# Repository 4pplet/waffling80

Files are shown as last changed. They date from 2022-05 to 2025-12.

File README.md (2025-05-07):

# Waffling80

Waffling80 is a multilayout TKL PCB with support for common ANSI and ISO layouts and split space. The goal is to provide a open source alternative that is compatible with many common TKL projects.

The project is split into four different PCB designs. Two MX-versions with different spacebar rotation, one ALPS-versions with north facing spacebar rotation (MX-style PCB mount stabs) and one HiTek-version.

***NOTE: This project is still mostly untested, check compatibility list. *** If you test this project in a case not listed in the compatiblity list. Please let me know here or at mail@4pplet.com

The distance between plate and PCB for a Hi-Tek board is 0.6mm bigger than a normal MX/Alps PCB.

Verified compatibility list: [Link](./COMPAT.md)

## Features:
- QMK & VIA
- USB-C break away
- APM or STM32F072
- RGB-led under/close to caps lock and scroll lock for MX and Alps-versions (requires transparent housings)
- On ALPS-version: Dual action switch support on ESC and Pause/Break switch positions.
- On MXHS-version: Capslock indicator led is placed at ESC switch position.
- Extensive layout support with F12 and F13, ISO and ANSI and more.

## Todo:
- Test compatibility in cases.

## Layout support - Solder PCB: 
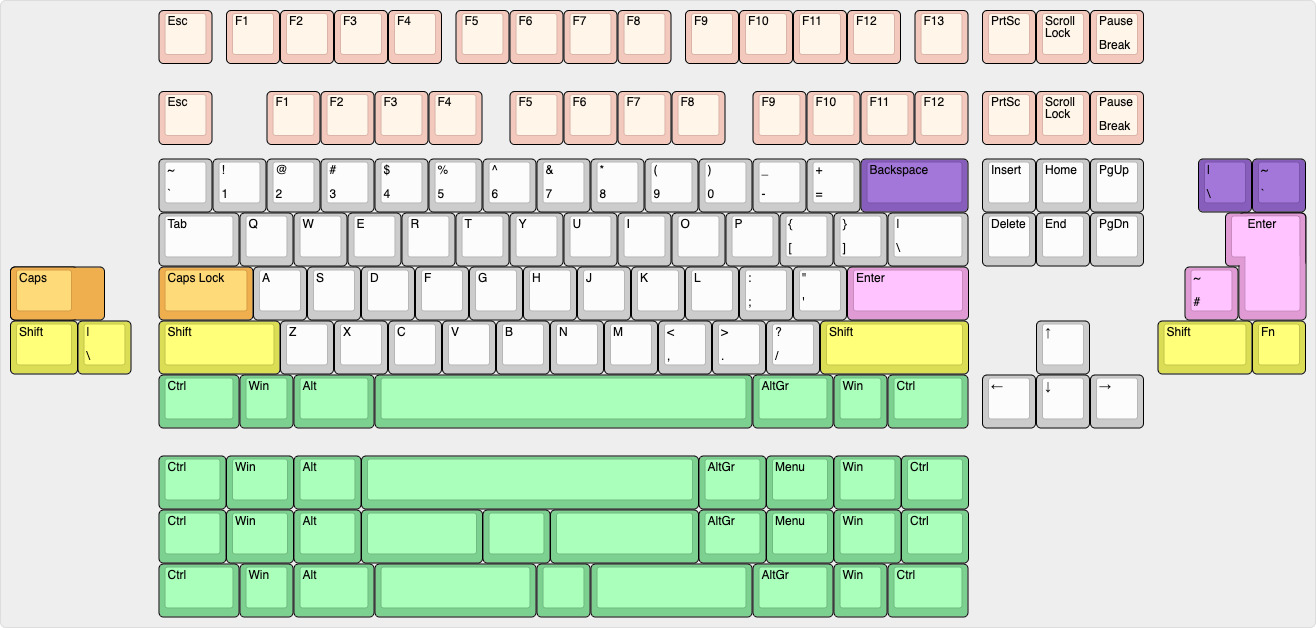
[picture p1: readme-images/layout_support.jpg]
Layout support - Solder


## Layout support - Hot swap PCB: 
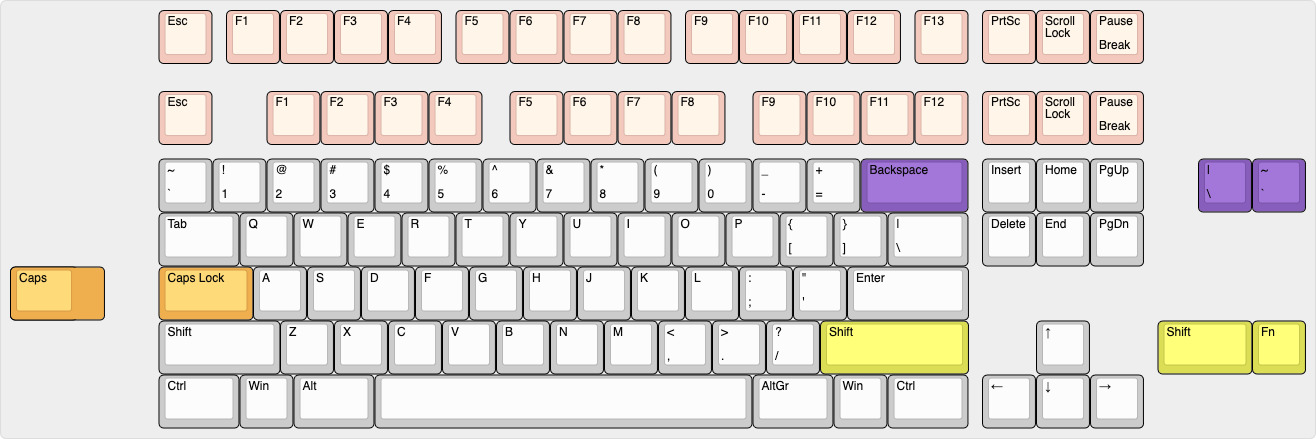
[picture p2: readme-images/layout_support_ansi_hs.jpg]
Layout support - Hot swap


## MX - North: 
MX - North
## MXHS - North: 
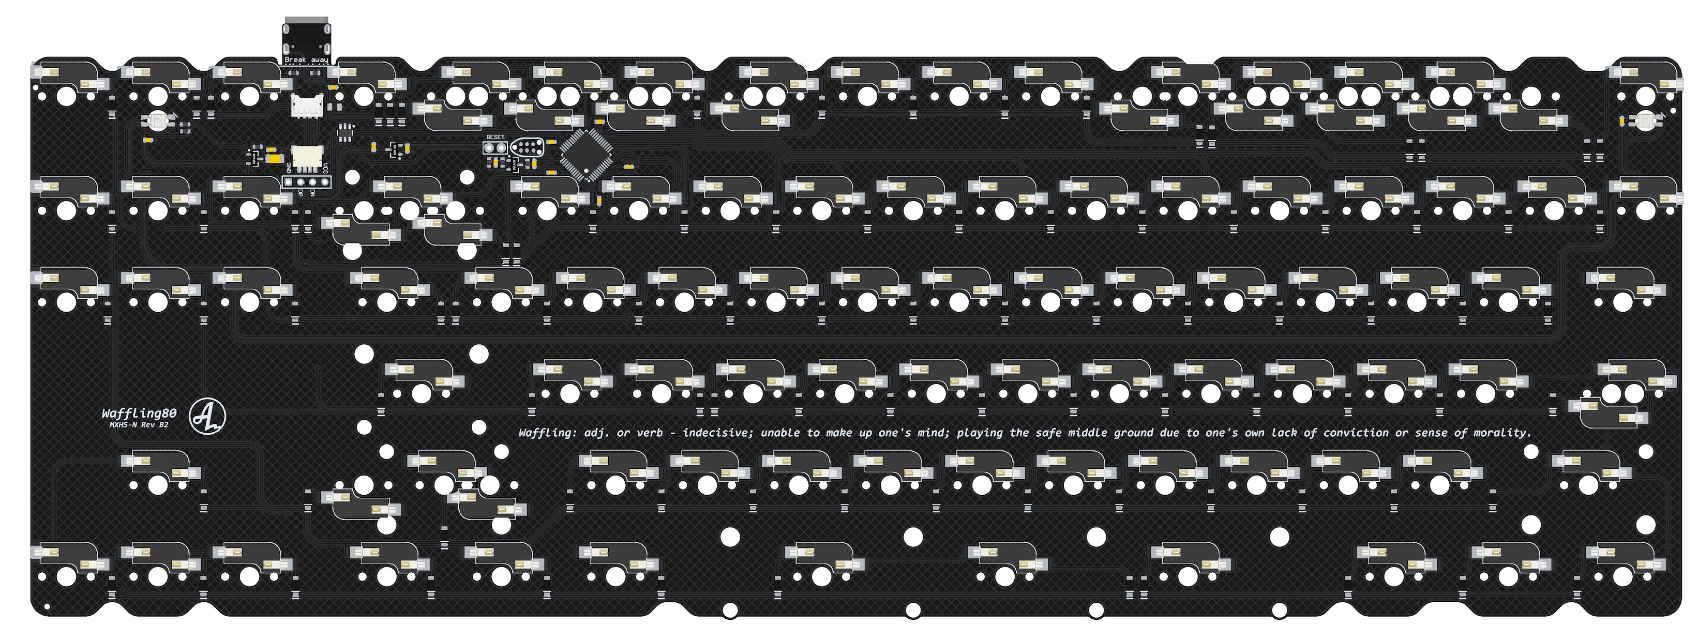
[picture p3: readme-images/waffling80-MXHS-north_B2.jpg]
MXHS - North

## MX - South:
MX - South
## ALPS:
ALPS
## NMB HiTek:
HiTek

## For ordering:
The files needed for manufacturing will be available in releases.

The following files are needed for the PCB Fab:
- BOM (contains component specifications)
- Pick and Place (contains component placement data)
- Gerber (contains PCB drawings and drill files)

## Releases
Files for manufacturing can be found in releases.

Releases are split into the following versions of the PCB: (note: not the same as configuration)
- Waffling80 MX - North, a MX solder PCB with north facing spacebar stabilizer support
- Waffling80 MXHS ANSI - North, a MX hotswap PCB with north facing spacebar stabilizer support
- Waffling80 MX - South, a MX solder PCB with south facing spacebar stabilizer support
- Waffling80 ALPS, a ALPS solder PCB with north facing MX-style spacebar stabilizer support
- Waffling80 HiTek, a solder PCB for HiTek Space Invader switches

## For clarity
- Revision: When updating the PCB I bump the revision. The revision is specified with a letter and a number. For big changes, the letter is changed (usually also include code changes), for minor changes, only the number is bumped.
- Version: Version specifies different switch types, PCB's specific to certain cases etc.

## Revision history:
- Rev A1: Initial prototype
- Rev A2: Increased size of the PCB cutouts for o-ring and mounting posts. Moved components that was interfering with screw in stabilizers for backspace. Removed flex cut. Added more layout options/compatibility on NMB-version (support for the common stepped keycaps)
- Rev B1: Changing MCU to APM or STM32F072
- Rev B2: Update F12/F13 and breakaway instruction on soldermask. Update outline slightly for better clip in stabilizer support. Adds additional molex DB connector.

<a href='https://ko-fi.com/4pplet' target='_blank'>Buy Me a Coffee at ko-fi.com

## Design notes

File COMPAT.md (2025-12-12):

# Waffling80 - Compatibility list

- **Geonworks Frog**. Used PCB: waffling80 MX north rev A1 (can bottom out with flex cut and soft half-plate)
- **Geonworks Frog**. Used PCB: waffling80 NMB rev A2. Insulating material/tape is recommended in the bottom of the case at the bottom row. SI builds is a bit higher/deeper than a MX-build, so with flex, the PCB can touch the bottom of the case.
- **Geonworks F1**. Used PCB:  waffling80 MX north rev A1
- **Monokei KFE CE**. Used PCB: waffling80 MX north rev A1
- **Lin Montage**. Used PCB: waffling80 MX north rev A2
- **Bias R2**. Used PCB: waffling80 MX north rev B1
- **Merisi Ottantaquattro**. Used PCB: waffling80 NMB rev B1 + proto plate
- **Gehirn**. Used PCB: Waffling80 MXHS North rev B2
- **Jane ME**. Used PCB: Waffling80 MXHS North rev B2

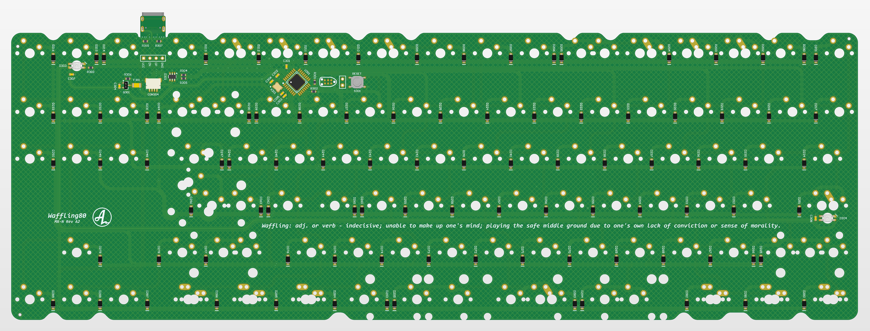
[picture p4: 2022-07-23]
readme-images/waffling80-MX-north_A2.jpg

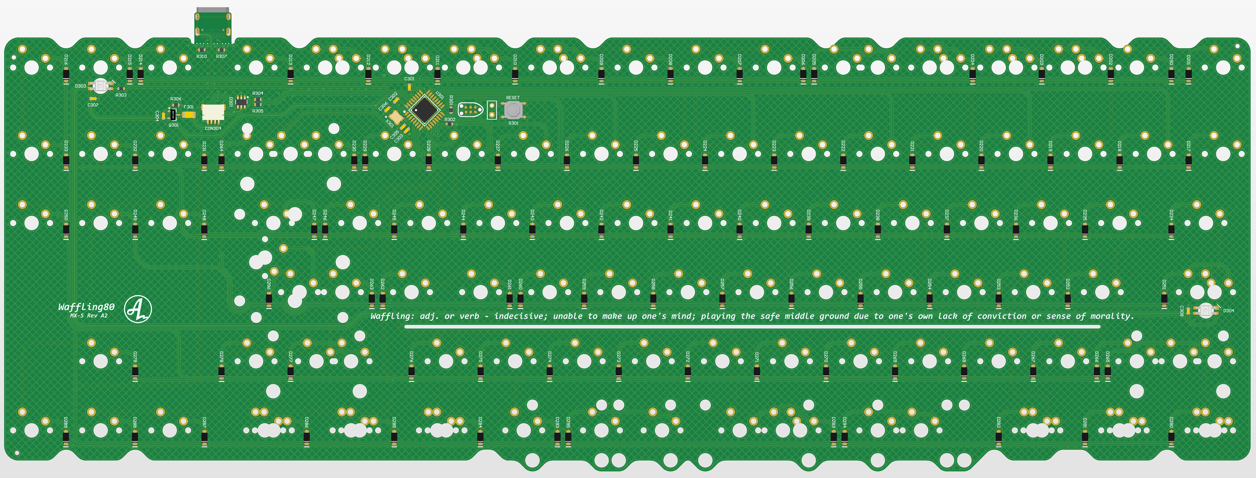
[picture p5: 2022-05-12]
readme-images/waffling80-MX-south_A2.jpg

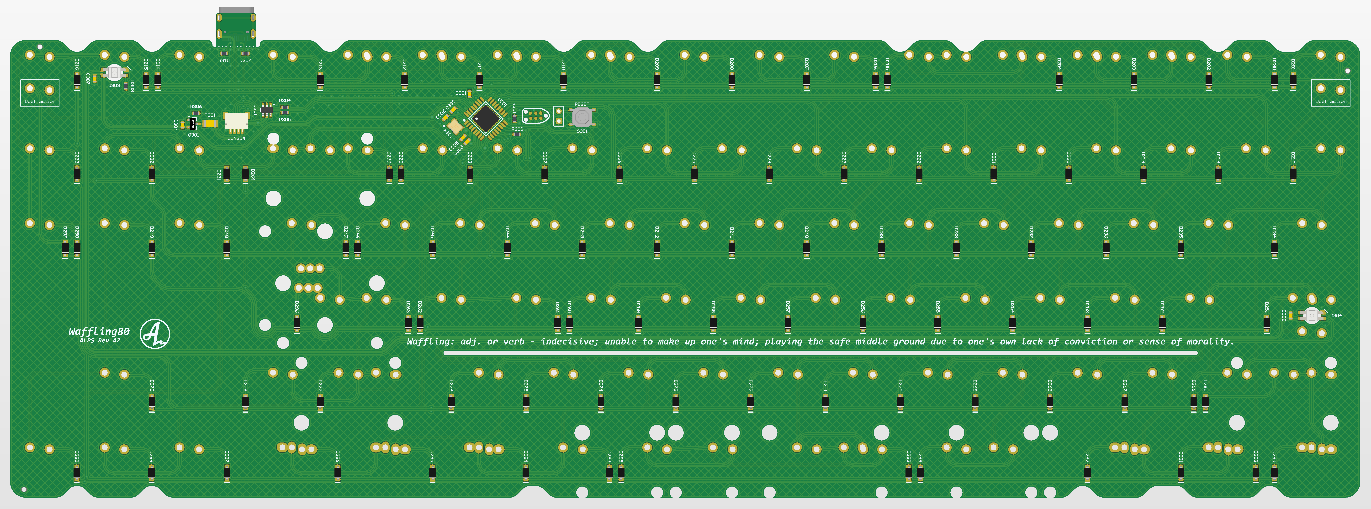
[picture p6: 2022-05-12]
readme-images/waffling80-ALPS-north_A2.jpg

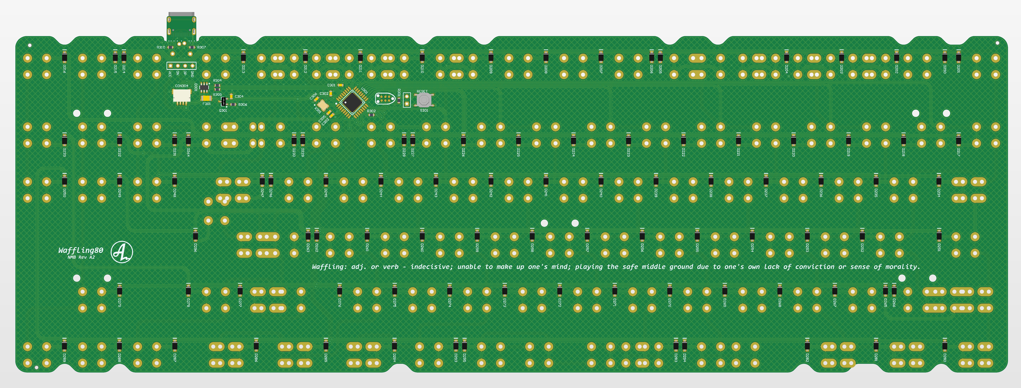
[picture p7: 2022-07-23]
readme-images/waffling80-NMB_A2.jpg

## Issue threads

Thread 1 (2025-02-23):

Would you consider support for Lofree Kailh Ghost / Phantom switches?

sandreas, 2025-02-23:
Hello,

first I would like to thank you for this amazing project and the great work.

Currently, I'm diving into custom keyboards and unfortunately for me I fell in love with a low profile switch with is mostly incompatible with all existing keyboards I checked. That's mostly because the Lofree Kailh Ghost is thicker than the default switches (image see below in the spoiled content).

Switch comparison:
<details>
<legend>switch comparison</legend>

Left: Kailh default
Right: Lofree Kailh Ghost

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

</details>

Maybe with your work it is possible to combine my favorite Layout (TKL 80% ISO german) with these Lofree Kailh Ghost switches.

It's the only Low-Profile switch that has the `THOCK` in my opinion... here is a review from Hipyo tech: https://www.youtube.com/watch?v=xxC8ItHUkiM&embeds_referring_euri=https%3A%2F%2Fwww.hardwareluxx.de%2F

Best,

sandreas

sandreas, 2025-03-06:
> This project aims to be used in specific TKL cases that use H88/H87 compatible PCBs.

Ah ok, I thought it was more like a general purpose PCB with specific cases that fit and the option of 3D printing a custom case. Thanks for the clarification.

> There are some interesting low profile switches and I may do projects for them in the future, but I don't think this one will get this specific switch compatibility.

This sounds great, I looked over your projects and I am pretty impressed - a lot of time has gone into these. Unfortunately I have a very specific use case / preference: 80% TKL ISO low-profile with FOSS Firmware. Currently only the `Keychron K1 Max` checks all the boxes. Unfortunately I did not like the available Gateron switches (neither of them) - I'm poisoned with the Lofree Kailh Ghost feeling, but these don't fit the K1 Max (yeah I know, I'm a nitpick). The Lofree Keyboards are not only expensive, but only available in ANSI. TKL 80% is not even in their portfolio.

So I did not find ANY available FOSS Firmware Keyboards having Kailh Ghost (or Choc V2) low profile compatible switches. If you know one, I could consider this problem solved... :-)

If you never tried the Kailh Ghost or Phantom low profile, I'd recommend to check them out. They THOCK ;-)

Best,

sandreas

sandreas, 2025-03-07:
> It's for sure also intended for general use with 3D print and other cases, but the USB-position and outline follow this attempt at a standard (H88/H87), similar to GH60-standard for 60% PCBs.

Ah ok, now I understand.

> I'm not saying there will never be low profile support, but there's no current plan for it in any of my projects.

That's totally fine, I'm happy that you published your other PCB layouts as a place to start. Thank you.

> I don't know of any ISO TKL PCBs that support these K1 Max switches.

No, NOT K1 Max Gateron, I'm looking for Choc V2 / Lofree Kailh Ghost compatible PCBs.
One keyboard that I considered was the [Kzzi I75](https://www.youtube.com/watch?v=fo6Ly_e7mYU), but it is only available in ANSI and hard to get here in Germany.

> Your best bet might be to use an existing open source TKL PCB and modify it.

That might be the best solution, but since I'm no PCB design expert (with little to no time due to 2 kids) I think this bite would be a little too much for my (referring to https://news.ycombinator.com/item?id=32507172). Maybe at some point in the future.

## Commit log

2022-05-12 updating A2 NMB release with support for a small USB DB
    [waffling80-NMB-USB.PcbDoc, waffling80-NMB-USB.PrjPcb, waffling80-NMB-USB.SchDoc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]
2022-05-23 adding additional layout compat
    adding additional layout compat for stepped keycaps
    [2_waffling80-NMB_matrix.SchDoc]
2022-05-27 Should be done, DRC checks needed
    [3_waffling80-ALPS_mcu.SchDoc, 3_waffling80-MX_mcu.SchDoc, 3_waffling80-NMB_mcu.SchDoc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]
2022-09-07 cont, DRC OK
    [3_waffling80-ALPS_mcu.SchDoc, 3_waffling80-MX_mcu.SchDoc, 3_waffling80-NMB_mcu.SchDoc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]
2024-04-11 Squashed commit of the following:
    commit 7d4ca092939213f1d86025833984b6eb2662241a
    Author: 4pplet <mail@4pplet.com>
    Date: Thu Apr 11 19:37:21 2024 +0200
    ready for releases
    commit 7b719760cb66d40229bd82c8d616657c576b82ec
    Author: 4pplet <mail@4pplet.com>
    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
    [1_waffling80-MXHS_top.SchDoc, 1_waffling80_classyTKL-NMB_top.SchDoc, 2_waffling80-MXHS_matrix.SchDoc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]
2024-04-11 update the classytkl nmb remix
    [3_waffling80_classyTKL-NMB_mcu.SchDoc]
